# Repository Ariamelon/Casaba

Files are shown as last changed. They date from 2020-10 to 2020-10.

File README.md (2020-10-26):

# Casaba
ADTB7M 1u Trackball Breakout

## Disclaimer
Just a breakout board for the BTO [ADTB7M](https://bit-trade-one.co.jp/selfmadekb/adtb7m/).

## Key Features
* Adapter board meant to fit either a normal keyswitch position or on a rotary encoder position.
* If soldered to the rotary encoder pads, it uses the rotary encoder A and B pins for the trackball module data and clock pins.
* On-board level shifter and voltage regulator.
* Breakout pins allow for direct soldering to the MCU if soldering to a normal switch position.

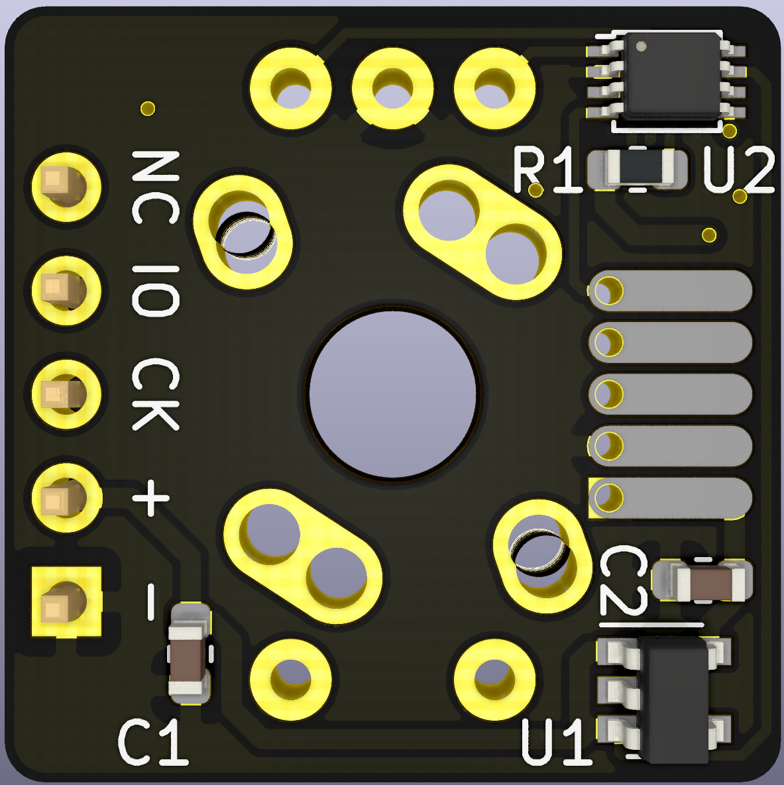
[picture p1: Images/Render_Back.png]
Casaba Back Render


## Changelog
* 26/10/2020: Initial commit

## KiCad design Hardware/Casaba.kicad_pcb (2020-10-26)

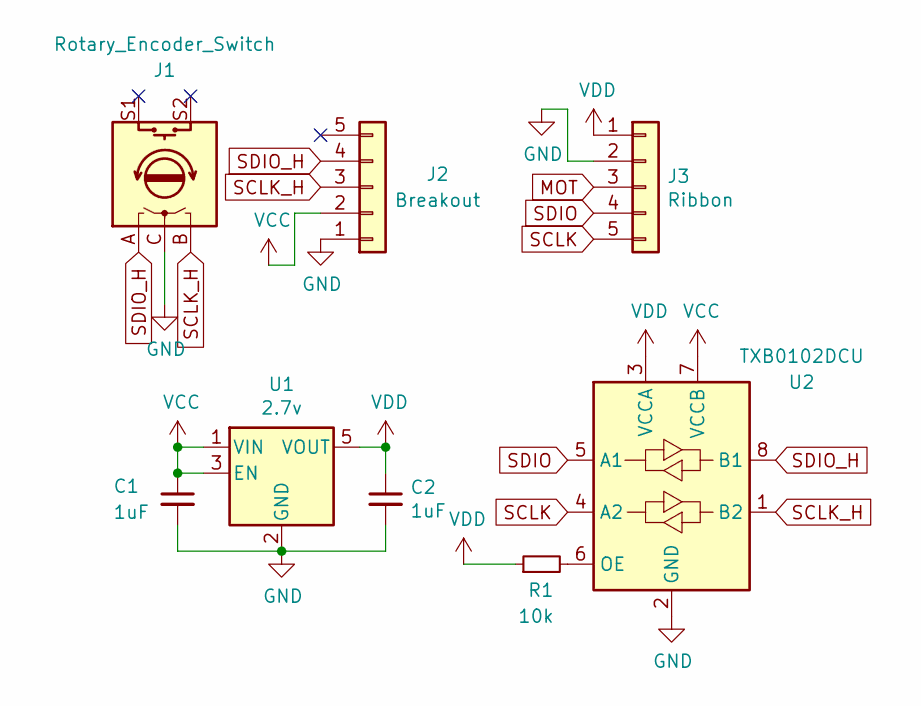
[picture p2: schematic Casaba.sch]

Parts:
C1, C2: 1uF; C_0603_1608Metric
J1: Rotary_Encoder_Switch; RotaryEncoder_Alps_EC11E-Switch_Vertical_H20mm
J2: Breakout; PinHeader_1x05_P2.54mm_Vertical
J3: Ribbon; PinHeader_1x05_P1.27mm_Vertical
R1: 10k; R_0603_1608Metric
U1: 2.7v; SOT-23-5
U2: TXB0102DCU; VSSOP-8_2.4x2.1mm_P0.5mm

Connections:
GND: C1.2, C2.2, J1.C, J2.1, J3.2, U1.2 (GND), U2.2 (GND)
MOT: J3.3
unnamed: R1.2, U2.6 (OE)
SCLK: J3.5, U2.4 (A2)
SCLK_H: J1.B, J2.3, U2.1 (B2)
SDIO: J3.4, U2.5 (A1)
SDIO_H: J1.A, J2.4, U2.8 (B1)
VCC: C1.1, J2.2, U1.1 (VIN), U1.3 (EN), U2.7 (VCCB)
VDD: C2.1, J3.1, R1.1, U1.5 (VOUT), U2.3 (VCCA)

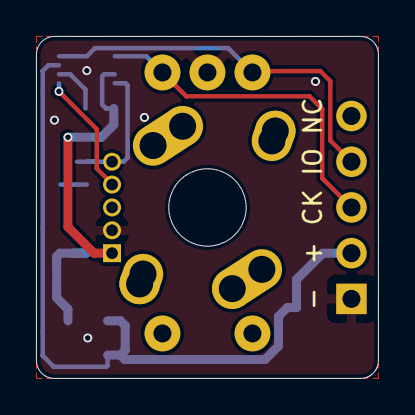
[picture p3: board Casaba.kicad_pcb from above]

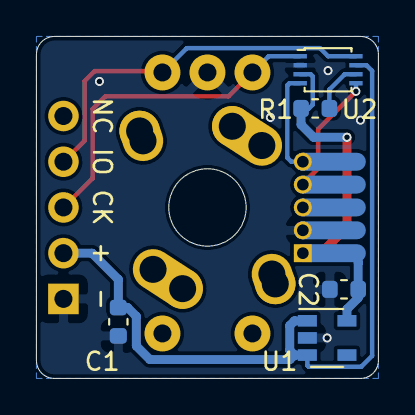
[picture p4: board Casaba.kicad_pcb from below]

Board: 2 copper layers, 19.0 x 19.0 mm, 8 parts (6 on the bottom side), 8 nets.
